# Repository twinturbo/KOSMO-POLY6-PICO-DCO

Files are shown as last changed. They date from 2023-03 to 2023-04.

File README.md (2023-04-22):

# KOSMO-POLY6-PICO-DCO 
This repository contains KICAD Schematics, PCB and front panel to build a 6 voice Raspberry Pi Pico Based Digitaly Controlled Oscilator for the "Polykit" Inspired 6 Channel Synth in Kosmo Format [Look Mum No Computer LMNK]. The credit for the desigin and code goes to the original Project by Jan Knipper AKA PolyKit [PolyKit DCO](https://github.com/polykit/pico-dco)

This project requires a Raspbery Pi Pico MCU.

Parts of the following information are by Jan AKA Polykit from the original repository

## About KOSMO-POLY6
The [POLY6](https://github.com/twinturbo/KOSMO-POLY6) GIT contains the details of the porject as a whole, this is one module.

Other modules in the line up are

- KOSMO-POLY6-PICO-DCO - Complete [ DCO ](https://github.com/twinturbo/KOSMO-POLY6-PICO-DCO)
- KOSMO-POLY6-DRUID-DCO -(TBD).
- KOSMO-POLY6-JACKS - Complete. [ JACKS ](https://github.com/twinturbo/KOSMO-POLY6-JACKS)
- KOSMO-POLY6-MIX - In design.
- KOSMO-POLY6-ADSR - In Production with JLCPCB.
- KOSMO-POLY6-VCA - In design.
- KOSMO-POLY6-CONTROLS - (TBD).
- KOSMO-POLY6 Filter - (TBD).
- KOSMO-POLY6-PG Programmer - (TBD)
- KOSMO-POLY6-MetricST-Front-Panel - (TBD)

# KOSMO-POLY6-PICO-DCO Details

The DCO utilises a Raspbery PI Pico using it's PWM Pins to generate a highly accurate frequency and gate signals. It can be controlled by USB MIDI or Standard 5 Pin serial MIDI. The analog oscillator part is based on the Juno 106 and generates sawtooth and square wave signal with a 10Vpp amplitude. Amplitude compensation is done by a smoothed PWM signal coming from the Pico.

## Key features

- Digitally controlled analog oscillator using a Raspberry Pi Pico
- Up to six voices
- Voice stacking             ------ [ requires sub control board ] See > Not Done
- Detuning of voices         ------ [ requires sub control board ] See > Not Done
- Frequency modulation (FM)  ------ [ requires sub control board ] See > Not Done
- Separate gate signal 
- DIN MIDI serial input
- USB MIDI input
- MIDI pitch bend (Via MIDI CC )
- Portamento with adjustable speed ( Via MIDI CC )
- Voltage and Midi telltale LED's
- Power pass through for sub modules.

## How does Jan's Sound & Look
These are examples of how the originator Jan Knipper's sound.
This is how it sounds: 

- [Ramp sample](https://soundcloud.com/polykit/pico-dco-ramp) 
- [Pulse sample](https://soundcloud.com/polykit/pico-dco-pulse) 
- [Polyphonic sample](https://soundcloud.com/polykit/pico-dco-polyphonic)

And in use with Jan 
- Youtube[Tube](https://www.youtube.com/watch?v=vj-DSh6yfM0)
- Youtube[Tube](https://www.youtube.com/watch?v=go1mErOdtsU)

## Schematics and PCB
Schematics in Kicad format can be found for the PCB and Front Panel

[MAIN-BOARD](HARDWARE/MAIN-BOARD) 
[MAIN-BOARD](HARDWARE/FRONT_PANEL) 

Gerber files for the PCB and front panel can be found [here](HARDWARE\PCB-PRINTS).

## Pictures 
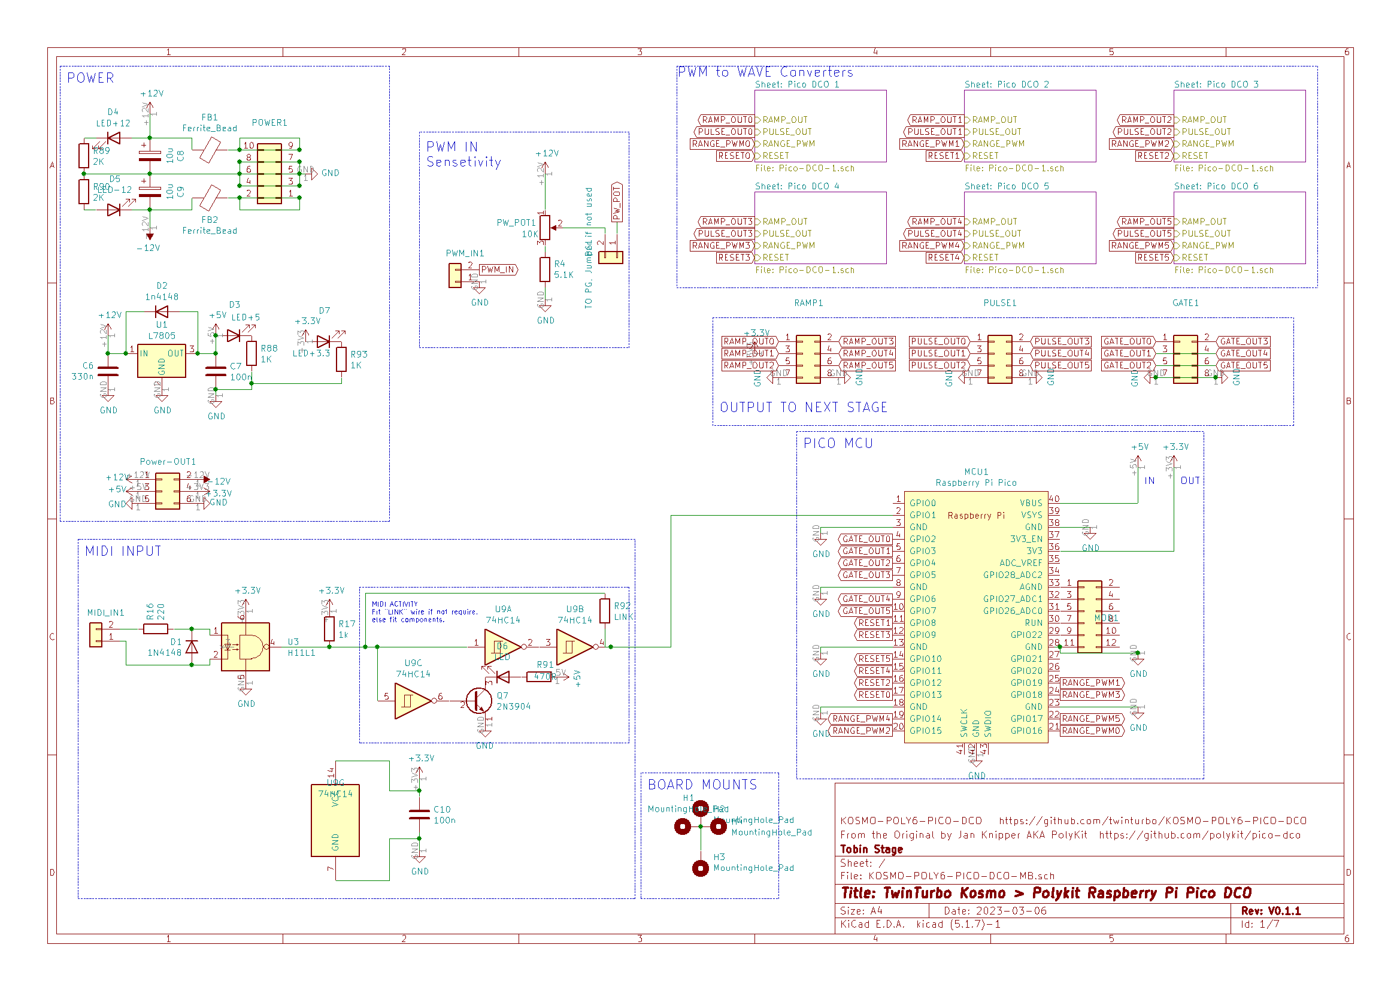
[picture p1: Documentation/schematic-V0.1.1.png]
KOSMO-POLY6-PICO SCHEMATIC

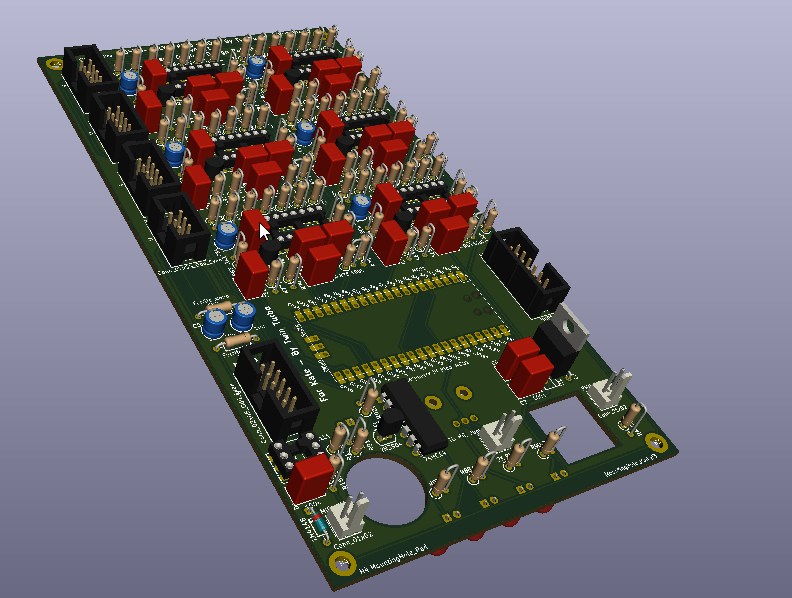
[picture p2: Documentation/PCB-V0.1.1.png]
KOSMO-POLY6-PICO PCB

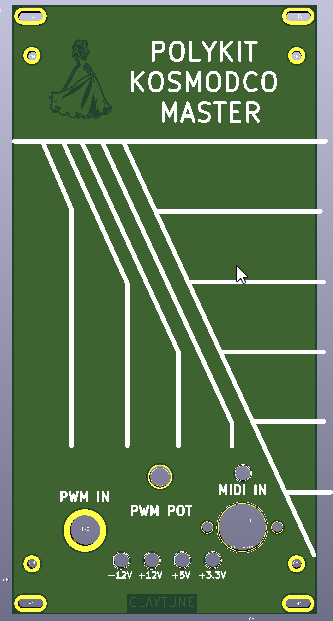
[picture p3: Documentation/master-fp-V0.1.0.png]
KOSMO-POLY6-PICO Front Panel

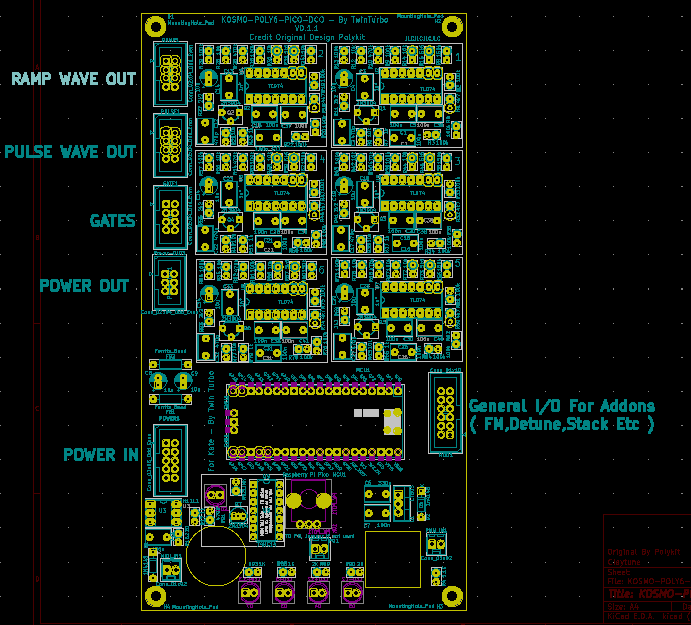
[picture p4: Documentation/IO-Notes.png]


## Installation on the paspbery Pi Pico (simple)
The software has been written in C++ and compiled into a uf2 format for the PICO, 

Two files are provided in the software/build folder along with the source code in the software folder

### Disabled Options
pico-dco-optdisab.uf2 is built with the options for FM, STACK and Detune disabled. This is ideal if you don't have these inputs connected.

//#define USE_ADC_STACK_VOICES // gpio 28 (adc 2)

//#define USE_ADC_DETUNE       // gpio 27 (adc 1)

//#define USE_ADC_FM           // gpio 26 (adc 0)

### Enabled Options
pico-dco-options.uf2 has the above options enabled.

#define USE_ADC_STACK_VOICES // gpio 28 (adc 2)

#define USE_ADC_DETUNE       // gpio 27 (adc 1)

#define USE_ADC_FM           // gpio 26 (adc 0)

### Writing to the MCU.

You will need the file on your computer, and whilst plugging in the PICO to USB hold the `BOOTSEL` button. 

The computer should recognise it as a Mass storage device, Copy desired UF2 file  onto the USB mass storage device. The PICO will reboot into operating mode. Note that if you run the bootsel again the file will not be there, it's not possible to confirm the upload.

## Usage

After building the module and installing the Pico should register as USB MIDI device. Alternatively serial MIDI input is available. The DCO listens to note on/note off messages on MIDI channel 1. Pitch bend is also supported. Portamento can be enabled by MIDI CC message #65, portamento time can be adjusted by CC message #5.

MIDI Device in Cakewalk
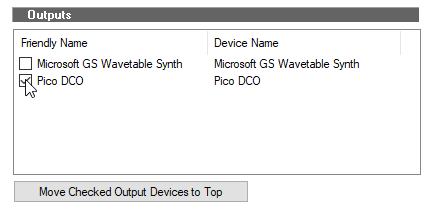
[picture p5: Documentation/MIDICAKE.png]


The 6 notes play all the time, hence there is a need for an ADSR and VCA to close the note off. Each new note played replaces the oldest in the group in a cyclic fashion.

## Detuning, stacking and FM

The built-in analog-to-digital converter can be used to modulate these parameters. You can add an external control voltage (0-3.3V) to that input pins. These features can be disabled by commenting (`//`) the following lines:

As mentioned above, these are not implemented in hardware on this module but a seperate control module needs to be built. 

#define USE_ADC_STACK_VOICES // gpio 28 (adc 2)

#define USE_ADC_DETUNE       // gpio 27 (adc 1)

#define USE_ADC_FM           // gpio 26 (adc 0)

Hardware wise the FM needs to be biased at 1.675v for zero input , the notes on this can be found in the source code **loop void adc_task()**

## Quirks

Initialy the voices will be floating on startup, which if directly outputed ( not through an ADSR/VCA ) may present as noise, as each of the voices is initialised by a key press the noise will go away. 

## Changes 
TwinTurbo 12/3/23 - 
Ref: > https://lookmumnocomputer.discourse.group/t/raspberry-pi-pico-dco/3421/90
updated source code from 0x90 to 0x9F

# References
The Original 
https://github.com/polykit/pico-dco

https://blog.thea.codes/the-design-of-the-juno-dco/

https://electricdruid.net/roland-juno-dcos/

https://www.youtube.com/watch?v=yYnQYF_Xa8g

https://github.com/raspberrypi/pico-examples/tree/master/pio/pwm

https://github.com/raspberrypi/pico-examples/tree/master/pio/pio_blink

https://github.com/raspberrypi/pico-examples/tree/master/pwm/hello_pwm

https://qiita.com/jamjam/items/f2fdd5c072ff348fd809

https://github.com/infovore/pico-example-midi

https://learn.sparkfun.com/tutorials/midi-tutorial/all

http://www.music-software-development.com/midi-tutorial.html

http://midi.teragonaudio.com/tech/midispec/run.htm

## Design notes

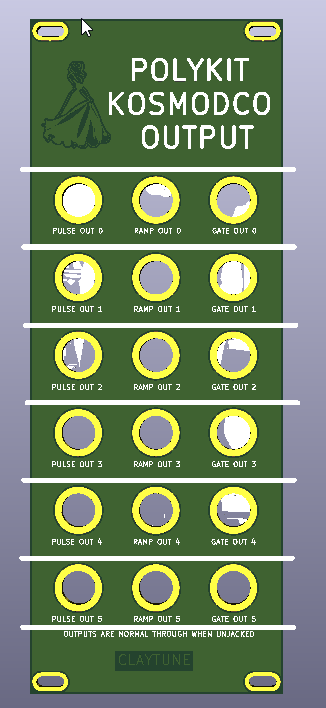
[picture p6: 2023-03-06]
Documentation/jack-fp-V0.1.0.png

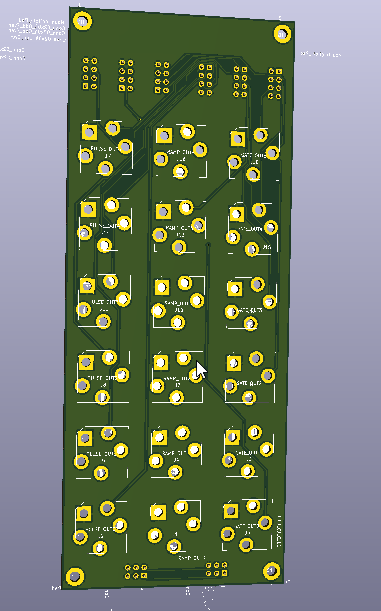
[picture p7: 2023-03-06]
Documentation/jack-pcb-V0.1.0.png

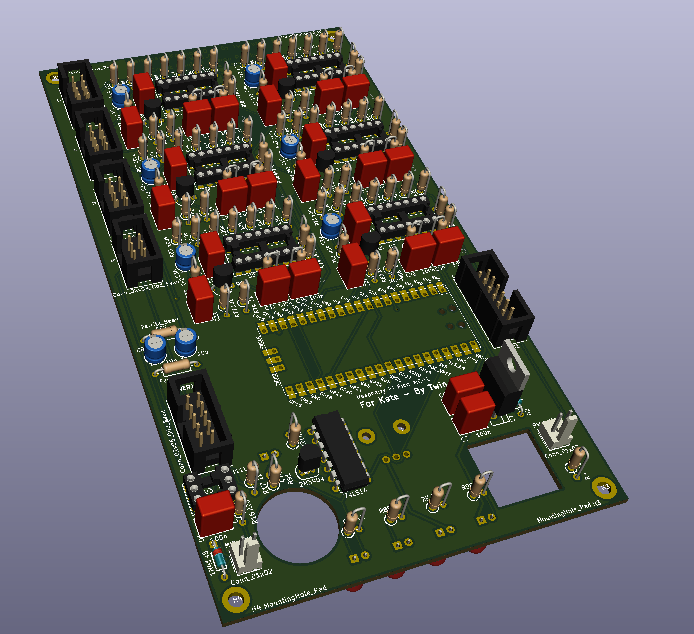
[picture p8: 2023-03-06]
Documentation/master-pcb-V0.1.0.png

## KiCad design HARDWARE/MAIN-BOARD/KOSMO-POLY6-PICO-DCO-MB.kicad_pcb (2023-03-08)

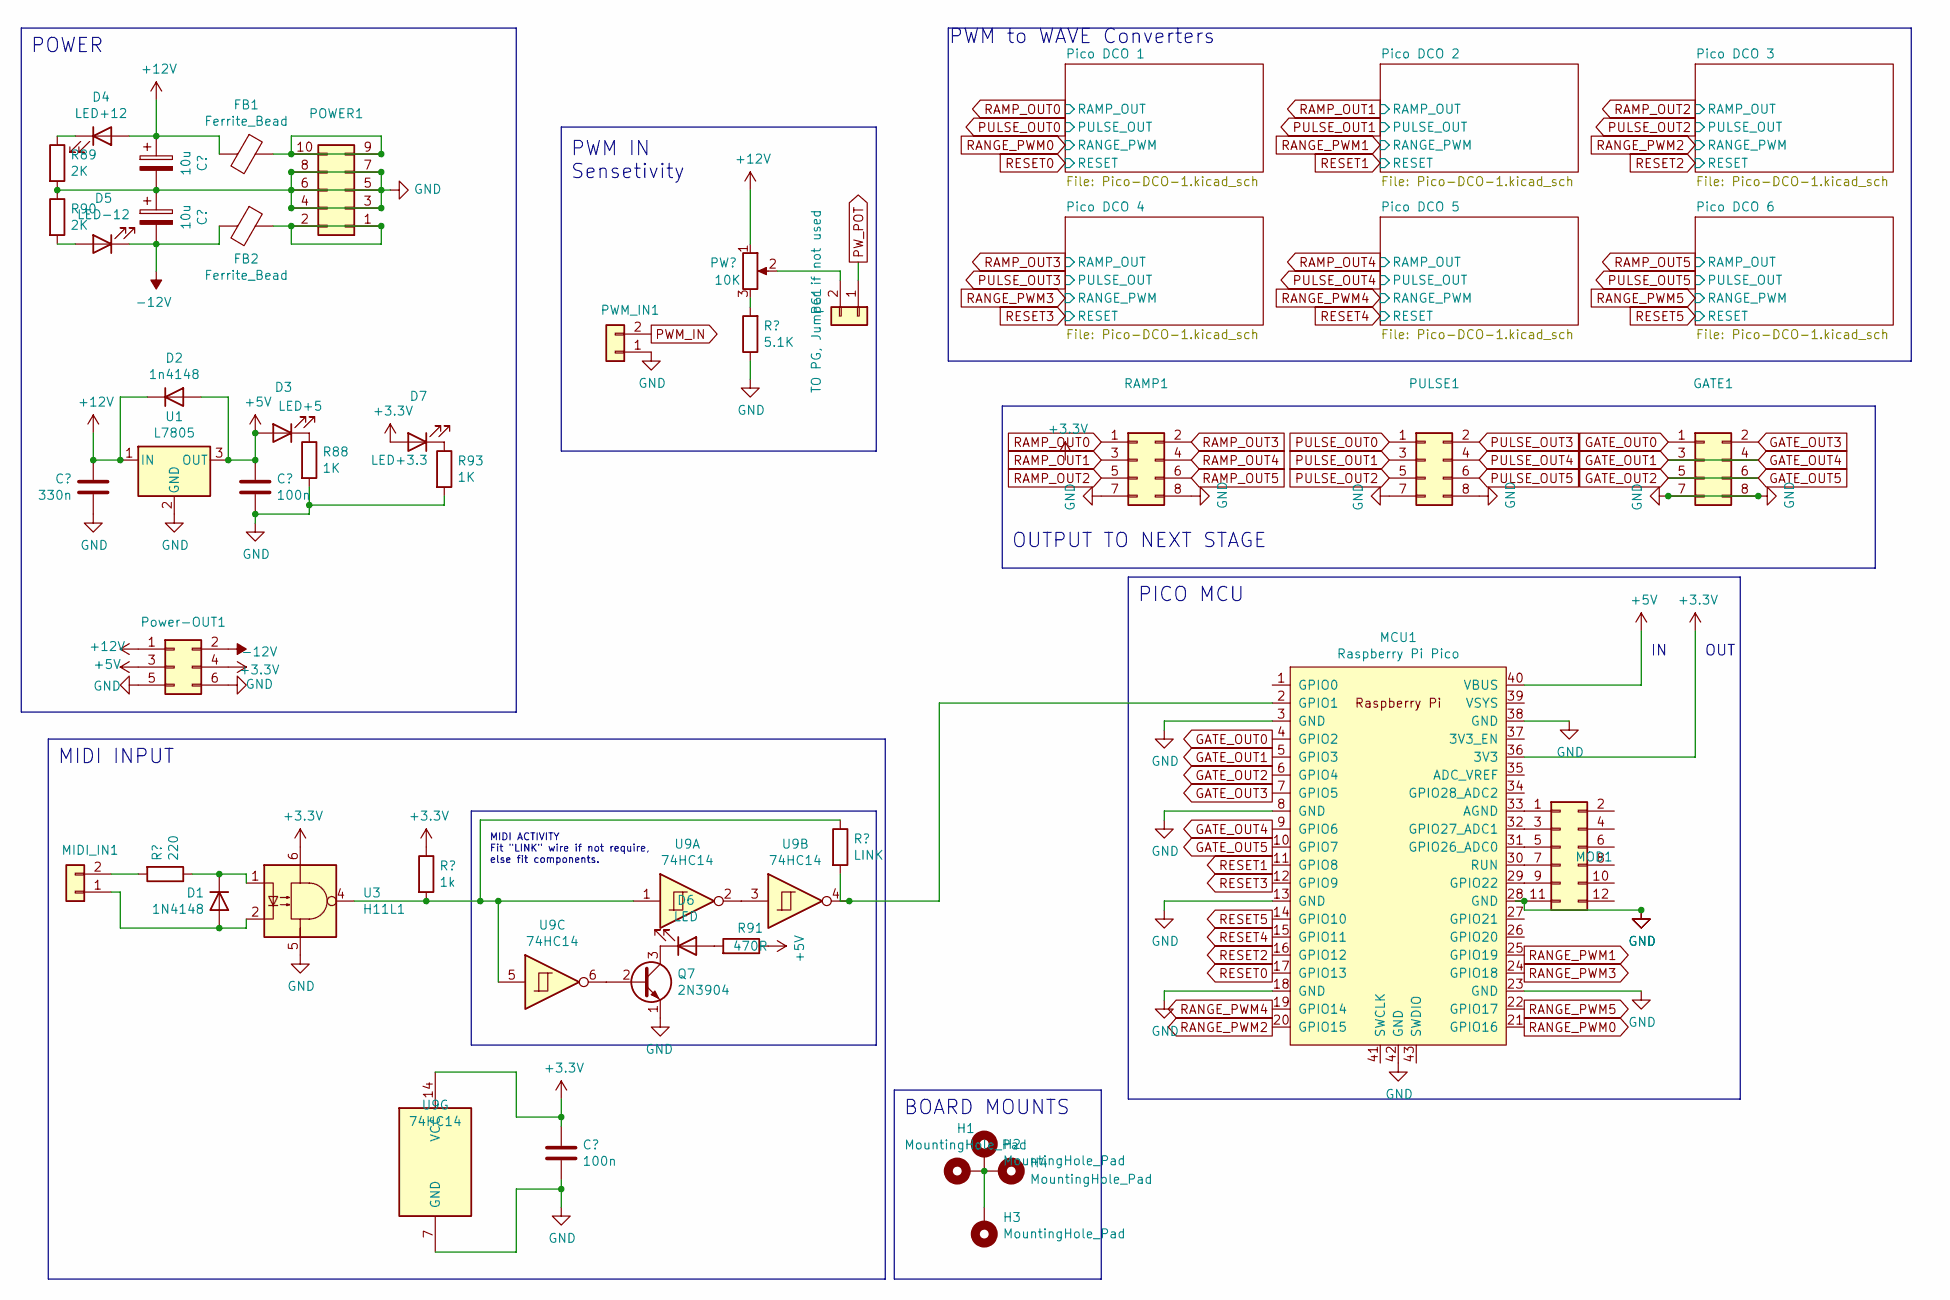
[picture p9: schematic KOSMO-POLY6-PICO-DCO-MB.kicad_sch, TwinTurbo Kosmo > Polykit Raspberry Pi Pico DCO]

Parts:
C6: 330n; C_Rect_L7.2mm_W4.5mm_P5.00mm_FKS2_FKP2_MKS2_MKP2
C7, C10: 100n; C_Rect_L7.2mm_W4.5mm_P5.00mm_FKS2_FKP2_MKS2_MKP2
C8, C9: 10u; CP_Radial_D5.0mm_P2.00mm
D1: 1N4148; D_DO-35_SOD27_P7.62mm_Horizontal
D2: 1n4148; D_DO-35_SOD27_P7.62mm_Horizontal
D3: LED+5; LED_D5.0mm
D4: LED+12; LED_D5.0mm
D5: LED-12; LED_D5.0mm
D6: LED; LED_D5.0mm
D7: LED+3.3; LED_D5.0mm
FB1, FB2: Ferrite_Bead; R_Axial_DIN0207_L6.3mm_D2.5mm_P10.16mm_Horizontal
GATE1: Conn_02x04_Odd_Even; IDC-Header_2x04_P2.54mm_Vertical
H1, H2, H3, H4: MountingHole_Pad; MountingHole_3.2mm_M3_DIN965_Pad
MCU1: Raspberry Pi Pico; RPi_Pico_SMD_TH
MIDI_IN1: Conn_01x02; Molex_KK-254_AE-6410-02A_1x02_P2.54mm_Vertical
MOD1: Conn_01x10; IDC-Header_2x06_P2.54mm_Vertical
PG1: TO PG, Jumper if not used; Molex_KK-254_AE-6410-02A_1x02_P2.54mm_Vertical
POWER1: Conn_02x05_Odd_Even; IDC-Header_2x05_P2.54mm_Vertical
PULSE1: Conn_02x04_Odd_Even; IDC-Header_2x04_P2.54mm_Vertical
PWM_IN1: Conn_01x02; Molex_KK-254_AE-6410-02A_1x02_P2.54mm_Vertical
PW_POT1: 10K; Potentiometer_Alps_RK09K_Single_Vertical
Power-OUT1: Conn_02x04_Odd_Even; IDC-Header_2x03_P2.54mm_Vertical
Q7: 2N3904; TO-92_Inline
R4: 5.1K; R_Axial_DIN0207_L6.3mm_D2.5mm_P2.54mm_Vertical
R16: 220; R_Axial_DIN0207_L6.3mm_D2.5mm_P2.54mm_Vertical
R17: 1k; R_Axial_DIN0207_L6.3mm_D2.5mm_P2.54mm_Vertical
R88, R93: 1K; R_Axial_DIN0207_L6.3mm_D2.5mm_P2.54mm_Vertical
R89, R90: 2K; R_Axial_DIN0207_L6.3mm_D2.5mm_P2.54mm_Vertical
R91: 470R; R_Axial_DIN0207_L6.3mm_D2.5mm_P2.54mm_Vertical
R92: LINK; R_Axial_DIN0207_L6.3mm_D2.5mm_P2.54mm_Vertical
RAMP1: Conn_02x04_Odd_Even; IDC-Header_2x04_P2.54mm_Vertical
U1: L7805; TO-220-3_Vertical
U3: H11L1; DIP-6_W7.62mm_Socket_LongPads
U9: 74HC14; DIP-14_W7.62mm

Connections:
+3V3: C10.1, D7.2 (A), MCU1.36 (3V3), Power-OUT1.4, R17.1, U3.6, U9.14 (VCC)
+5V: C7.1, D2.2 (A), D3.2 (A), MCU1.40 (VBUS), Power-OUT1.3, R91.1, U1.3 (OUT)
+12V: C6.2, C8.1, D2.1 (K), D4.2 (A), FB1.2, PW_POT1.1, Power-OUT1.1, U1.1 (IN); also elsewhere on the board
-12V: C9.2, D5.1 (K), FB2.2, Power-OUT1.2; also elsewhere on the board
GATE_OUT0: GATE1.1, MCU1.4 (GPIO2)
GATE_OUT1: GATE1.3, GATE1.4, MCU1.5 (GPIO3), MCU1.9 (GPIO6)
GATE_OUT2: GATE1.5, GATE1.6, MCU1.6 (GPIO4), MCU1.10 (GPIO7)
GATE_OUT3: GATE1.2, MCU1.7 (GPIO5)
GND: C6.1, C7.2, C8.2, C9.1, C10.2, GATE1.7, GATE1.8, MCU1.3 (GND), MCU1.8 (GND), MCU1.13 (GND), MCU1.18 (GND), MCU1.23 (GND), MCU1.28 (GND), MCU1.38 (GND), MCU1.42 (GND), MOD1.11, POWER1.3, POWER1.4, POWER1.5, POWER1.6, POWER1.7, POWER1.8, PULSE1.7, PULSE1.8, PWM_IN1.1, Power-OUT1.5, Power-OUT1.6, Q7.1 (E), R4.1, R88.2, R89.2, R90.1, R93.2, RAMP1.7, RAMP1.8, U1.2 (GND), U3.5, U9.7 (GND); also elsewhere on the board
unnamed: D1.1 (K), R16.1, U3.1
unnamed: D1.2 (A), MIDI_IN1.1, U3.2
unnamed: D3.1 (K), R88.1
unnamed: D4.1 (K), R89.1
unnamed: D5.2 (A), R90.2
unnamed: D6.1 (K), Q7.3 (C)
unnamed: D6.2 (A), R91.2
unnamed: D7.1 (K), R93.1
unnamed: FB1.1, POWER1.9, POWER1.10
unnamed: FB2.1, POWER1.1, POWER1.2
unnamed: H1.1, H2.1, H3.1, H4.1
unnamed: MCU1.2 (GPIO1), R92.2, U9.4
unnamed: MCU1.29 (GPIO22), MOD1.9
unnamed: MCU1.30 (RUN), MOD1.7
unnamed: MCU1.31 (GPIO26_ADC0), MOD1.5
unnamed: MCU1.32 (GPIO27_ADC1), MOD1.3
unnamed: MCU1.33 (AGND), MOD1.1
unnamed: MIDI_IN1.2, R16.2
unnamed: PG1.2, PW_POT1.2
unnamed: PW_POT1.3, R4.2
unnamed: Q7.2 (B), U9.6
unnamed: R17.2, R92.1, U3.4, U9.1, U9.5
unnamed: U9.2, U9.3
PULSE_OUT0: PULSE1.1; also elsewhere on the board
PULSE_OUT1: PULSE1.3; also elsewhere on the board
PULSE_OUT2: PULSE1.5; also elsewhere on the board
PULSE_OUT3: PULSE1.2; also elsewhere on the board
PULSE_OUT4: PULSE1.4; also elsewhere on the board
PULSE_OUT5: PULSE1.6; also elsewhere on the board
PWM_IN: PWM_IN1.2; also elsewhere on the board
PW_POT: PG1.1; also elsewhere on the board
RAMP_OUT0: RAMP1.1; also elsewhere on the board
RAMP_OUT1: RAMP1.3; also elsewhere on the board
RAMP_OUT2: RAMP1.5; also elsewhere on the board
RAMP_OUT3: RAMP1.2; also elsewhere on the board
RAMP_OUT4: RAMP1.4; also elsewhere on the board
RAMP_OUT5: RAMP1.6; also elsewhere on the board
RANGE_PWM0: MCU1.21 (GPIO16); also elsewhere on the board
RANGE_PWM1: MCU1.25 (GPIO19); also elsewhere on the board
RANGE_PWM2: MCU1.20 (GPIO15); also elsewhere on the board
RANGE_PWM3: MCU1.24 (GPIO18); also elsewhere on the board
RANGE_PWM4: MCU1.19 (GPIO14); also elsewhere on the board
RANGE_PWM5: MCU1.22 (GPIO17); also elsewhere on the board
RESET0: MCU1.17 (GPIO13); also elsewhere on the board
RESET1: MCU1.11 (GPIO8); also elsewhere on the board
RESET2: MCU1.16 (GPIO12); also elsewhere on the board
RESET3: MCU1.12 (GPIO9); also elsewhere on the board
RESET4: MCU1.15 (GPIO11); also elsewhere on the board
RESET5: MCU1.14 (GPIO10); also elsewhere on the board

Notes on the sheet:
POWER
PICO MCU
OUT
PWM to WAVE Converters
MIDI ACTIVITY Fit "LINK" wire if not require, else fit components.
BOARD MOUNTS
PWM IN Sensetivity
MIDI INPUT
OUTPUT TO NEXT STAGE

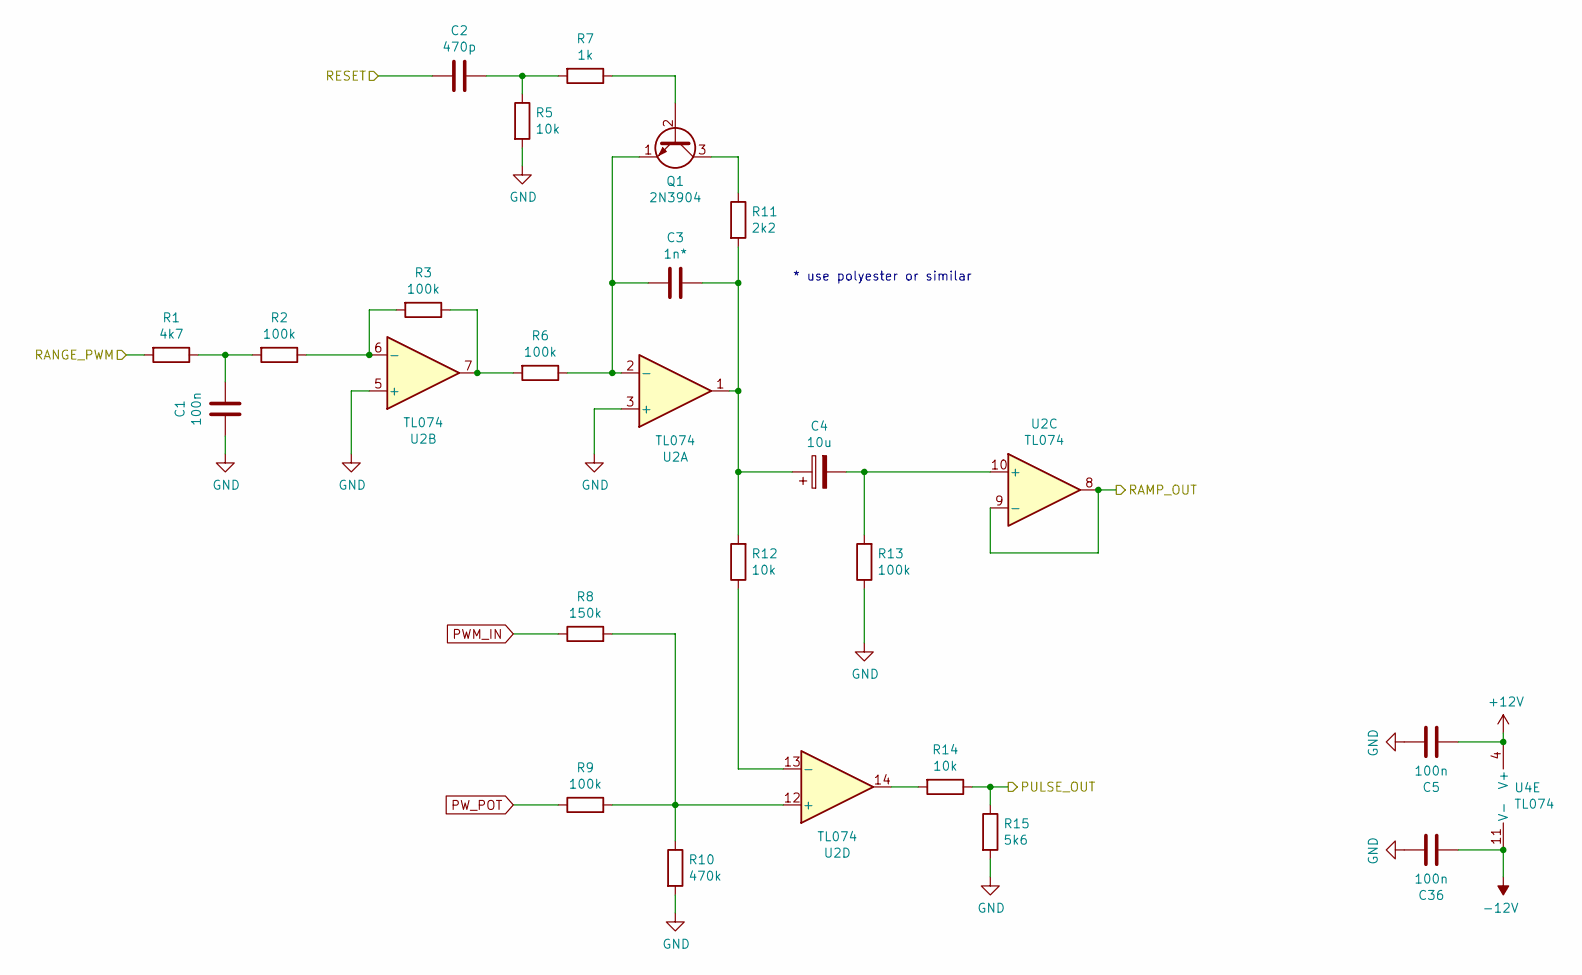
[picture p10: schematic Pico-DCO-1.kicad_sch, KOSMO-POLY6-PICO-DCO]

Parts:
C1, C5, C36: 100n; C_Rect_L7.2mm_W4.5mm_P5.00mm_FKS2_FKP2_MKS2_MKP2
C2: 470p; C_Rect_L7.2mm_W4.5mm_P5.00mm_FKS2_FKP2_MKS2_MKP2
C3: 1n*; C_Rect_L7.2mm_W4.5mm_P5.00mm_FKS2_FKP2_MKS2_MKP2
C4: 10u; CP_Radial_D5.0mm_P2.00mm
Q1: 2N3904; TO-92_Wide
R1: 4k7; R_Axial_DIN0207_L6.3mm_D2.5mm_P2.54mm_Vertical
R2, R3, R6, R9, R13: 100k; R_Axial_DIN0207_L6.3mm_D2.5mm_P2.54mm_Vertical
R5, R12, R14: 10k; R_Axial_DIN0207_L6.3mm_D2.5mm_P2.54mm_Vertical
R7: 1k; R_Axial_DIN0207_L6.3mm_D2.5mm_P2.54mm_Vertical
R8: 150k; R_Axial_DIN0207_L6.3mm_D2.5mm_P2.54mm_Vertical
R10: 470k; R_Axial_DIN0207_L6.3mm_D2.5mm_P2.54mm_Vertical
R11: 2k2; R_Axial_DIN0207_L6.3mm_D2.5mm_P2.54mm_Vertical
R15: 5k6; R_Axial_DIN0207_L6.3mm_D2.5mm_P2.54mm_Vertical
U2, U4: TL074; DIP-14_W7.62mm_Socket_LongPads

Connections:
+12V: C5.2, U2.4 (V+), U4.4 (V+); also elsewhere on the board
-12V: C36.2, U2.11 (V-), U4.11 (V-); also elsewhere on the board
GND: C1.2, C5.1, C36.1, R5.2, R10.2, R13.1, R15.2, U2.3 (+), U2.5 (+), U4.3 (+), U4.5 (+); also elsewhere on the board
unnamed: C1.1, R1.1, R2.2
unnamed: C2.1, R5.1, R7.2
unnamed: C3.1, C4.1, R11.2, R12.2, U2.1
unnamed: C3.2, Q1.1 (E), R6.1, U2.2 (-)
unnamed: C4.2, R13.2, U2.10 (+)
unnamed 16: U4.1; also elsewhere on the board
unnamed 17: U4.2 (-); also elsewhere on the board
unnamed 18: U4.10 (+); also elsewhere on the board
unnamed: Q1.2 (B), R7.1
unnamed: Q1.3 (C), R11.1
unnamed: R2.1, R3.2, U2.6 (-)
unnamed: R3.1, R6.2, U2.7
unnamed: R8.2, R9.2, R10.1, U2.12 (+)
unnamed: R12.1, U2.13 (-)
unnamed: R14.2, U2.14
unnamed 93: U4.6 (-); also elsewhere on the board
unnamed 94: U4.7; also elsewhere on the board
unnamed 95: U4.12 (+); also elsewhere on the board
unnamed 96: U4.13 (-); also elsewhere on the board
unnamed 97: U4.14; also elsewhere on the board
PULSE_OUT0: R14.1, R15.1; also elsewhere on the board
PWM_IN: R8.1; also elsewhere on the board
PW_POT: R9.1; also elsewhere on the board
RAMP_OUT0: U2.8, U2.9 (-); also elsewhere on the board
RAMP_OUT1: U4.8, U4.9 (-); also elsewhere on the board
RANGE_PWM0: R1.2; also elsewhere on the board
RESET0: C2.2; also elsewhere on the board

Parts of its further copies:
C11, C15, C16, C20, C21, C25, C26, C30, C31, C35, C37, C38, C39, C40, C41: 100n; C_Rect_L7.2mm_W4.5mm_P5.00mm_FKS2_FKP2_MKS2_MKP2
C12, C17, C22, C27, C32: 470p; C_Rect_L7.2mm_W4.5mm_P5.00mm_FKS2_FKP2_MKS2_MKP2
C13, C18, C23, C28, C33: 1n*; C_Rect_L7.2mm_W4.5mm_P5.00mm_FKS2_FKP2_MKS2_MKP2
C14, C19, C24, C29, C34: 10u; CP_Radial_D5.0mm_P2.00mm
Q2, Q3, Q4, Q5, Q6: 2N3904; TO-92_Wide
R18, R32, R46, R60, R74: 4k7; R_Axial_DIN0207_L6.3mm_D2.5mm_P2.54mm_Vertical
R19, R20, R22, R25, R29, R33, R34, R36, R39, R43, R47, R48, R50, R53, R57, R61, R62, R64, R67, R71, R75, R76, R78, R81, R85: 100k; R_Axial_DIN0207_L6.3mm_D2.5mm_P2.54mm_Vertical
R21, R28, R30, R35, R42, R44, R49, R56, R58, R63, R70, R72, R77, R84, R86: 10k; R_Axial_DIN0207_L6.3mm_D2.5mm_P2.54mm_Vertical
R23, R37, R51, R65, R79: 1k; R_Axial_DIN0207_L6.3mm_D2.5mm_P2.54mm_Vertical
R24, R38, R52, R66, R80: 150k; R_Axial_DIN0207_L6.3mm_D2.5mm_P2.54mm_Vertical
R26, R40, R54, R68, R82: 470k; R_Axial_DIN0207_L6.3mm_D2.5mm_P2.54mm_Vertical
R27, R41, R55, R69, R83: 2k2; R_Axial_DIN0207_L6.3mm_D2.5mm_P2.54mm_Vertical
R31, R45, R59, R73, R87: 5k6; R_Axial_DIN0207_L6.3mm_D2.5mm_P2.54mm_Vertical
U5, U6, U7, U8: TL074; DIP-14_W7.62mm_Socket_LongPads

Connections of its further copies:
+12V: C15.2, C20.2, C25.2, C30.2, C35.2, U5.4 (V+), U6.4 (V+), U7.4 (V+), U8.4 (V+); also elsewhere on the board
-12V: C37.2, C38.2, C39.2, C40.2, C41.2, U5.11 (V-), U6.11 (V-), U7.11 (V-), U8.11 (V-); also elsewhere on the board
GND: C11.2, C15.1, C16.2, C20.1, C21.2, C25.1, C26.2, C30.1, C31.2, C35.1, C37.1, C38.1, C39.1, C40.1, C41.1, R21.2, R26.2, R29.1, R31.2, R35.2, R40.2, R43.1, R45.2, R49.2, R54.2, R57.1, R59.2, R63.2, R68.2, R71.1, R73.2, R77.2, R82.2, R85.1, R87.2, U5.3 (+), U5.5 (+), U6.3 (+), U6.5 (+), U7.3 (+), U7.5 (+), U8.3 (+), U8.5 (+); also elsewhere on the board
unnamed: C11.1, R18.1, R19.2
unnamed: C12.1, R21.1, R23.2
unnamed 16: C13.1, C14.1, R27.2, R28.2; also elsewhere on the board
unnamed 17: C13.2, Q2.1 (E), R22.1; also elsewhere on the board
unnamed 18: C14.2, R29.2; also elsewhere on the board
unnamed: C16.1, R32.1, R33.2
unnamed: C17.1, R35.1, R37.2
unnamed: C18.1, C19.1, R41.2, R42.2, U5.1
unnamed: C18.2, Q3.1 (E), R36.1, U5.2 (-)
unnamed: C19.2, R43.2, U5.10 (+)
unnamed: C21.1, R46.1, R47.2
unnamed: C22.1, R49.1, R51.2
unnamed: C23.1, C24.1, R55.2, R56.2, U6.1
unnamed: C23.2, Q4.1 (E), R50.1, U6.2 (-)
unnamed: C24.2, R57.2, U6.10 (+)
unnamed: C26.1, R60.1, R61.2
unnamed: C27.1, R63.1, R65.2
unnamed: C28.1, C29.1, R69.2, R70.2, U7.1
unnamed: C28.2, Q5.1 (E), R64.1, U7.2 (-)
unnamed: C29.2, R71.2, U7.10 (+)
unnamed: C31.1, R74.1, R75.2
unnamed: C32.1, R77.1, R79.2
unnamed: C33.1, C34.1, R83.2, R84.2, U8.1
unnamed: C33.2, Q6.1 (E), R78.1, U8.2 (-)
unnamed: C34.2, R85.2, U8.10 (+)
unnamed: Q2.2 (B), R23.1
unnamed: Q2.3 (C), R27.1
unnamed: Q3.2 (B), R37.1
unnamed: Q3.3 (C), R41.1
unnamed: Q4.2 (B), R51.1
unnamed: Q4.3 (C), R55.1
unnamed: Q5.2 (B), R65.1
unnamed: Q5.3 (C), R69.1
unnamed: Q6.2 (B), R79.1
unnamed: Q6.3 (C), R83.1
unnamed 93: R19.1, R20.2; also elsewhere on the board
unnamed 94: R20.1, R22.2; also elsewhere on the board
unnamed 95: R24.2, R25.2, R26.1; also elsewhere on the board
unnamed 96: R28.1; also elsewhere on the board
unnamed 97: R30.2; also elsewhere on the board
unnamed: R33.1, R34.2, U5.6 (-)
unnamed: R34.1, R36.2, U5.7
unnamed: R38.2, R39.2, R40.1, U5.12 (+)
unnamed: R42.1, U5.13 (-)
unnamed: R44.2, U5.14
unnamed: R47.1, R48.2, U6.6 (-)
unnamed: R48.1, R50.2, U6.7
unnamed: R52.2, R53.2, R54.1, U6.12 (+)
unnamed: R56.1, U6.13 (-)
unnamed: R58.2, U6.14
unnamed: R61.1, R62.2, U7.6 (-)
unnamed: R62.1, R64.2, U7.7
unnamed: R66.2, R67.2, R68.1, U7.12 (+)
unnamed: R70.1, U7.13 (-)
unnamed: R72.2, U7.14
unnamed: R75.1, R76.2, U8.6 (-)
unnamed: R76.1, R78.2, U8.7
unnamed: R80.2, R81.2, R82.1, U8.12 (+)
unnamed: R84.1, U8.13 (-)
unnamed: R86.2, U8.14
PULSE_OUT1: R30.1, R31.1; also elsewhere on the board
PULSE_OUT2: R44.1, R45.1; also elsewhere on the board
PULSE_OUT3: R58.1, R59.1; also elsewhere on the board
PULSE_OUT4: R72.1, R73.1; also elsewhere on the board
PULSE_OUT5: R86.1, R87.1; also elsewhere on the board
PWM_IN: R24.1, R38.1, R52.1, R66.1, R80.1; also elsewhere on the board
PW_POT: R25.1, R39.1, R53.1, R67.1, R81.1; also elsewhere on the board
RAMP_OUT2: U5.8, U5.9 (-); also elsewhere on the board
RAMP_OUT3: U6.8, U6.9 (-); also elsewhere on the board
RAMP_OUT4: U7.8, U7.9 (-); also elsewhere on the board
RAMP_OUT5: U8.8, U8.9 (-); also elsewhere on the board
RANGE_PWM1: R18.2; also elsewhere on the board
RANGE_PWM2: R32.2; also elsewhere on the board
RANGE_PWM3: R46.2; also elsewhere on the board
RANGE_PWM4: R60.2; also elsewhere on the board
RANGE_PWM5: R74.2; also elsewhere on the board
RESET1: C12.2; also elsewhere on the board
RESET2: C17.2; also elsewhere on the board
RESET3: C22.2; also elsewhere on the board
RESET4: C27.2; also elsewhere on the board
RESET5: C32.2; also elsewhere on the board

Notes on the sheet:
* use polyester or similar

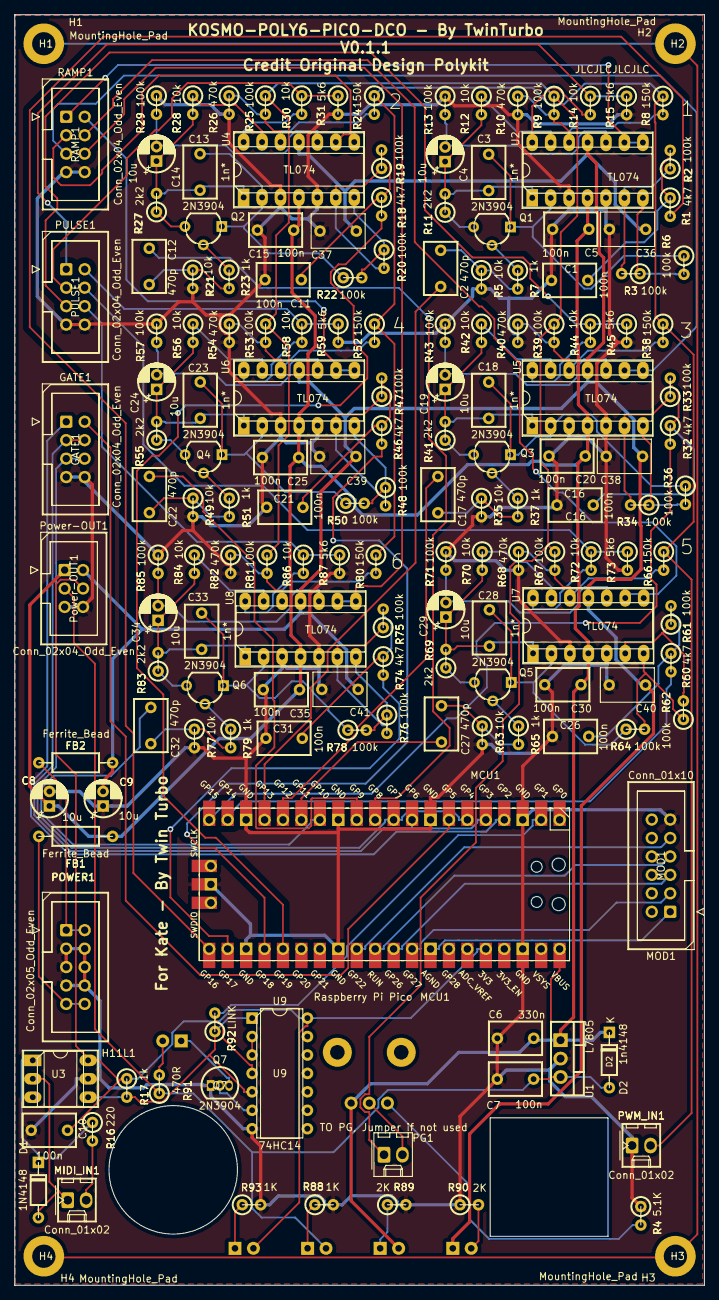
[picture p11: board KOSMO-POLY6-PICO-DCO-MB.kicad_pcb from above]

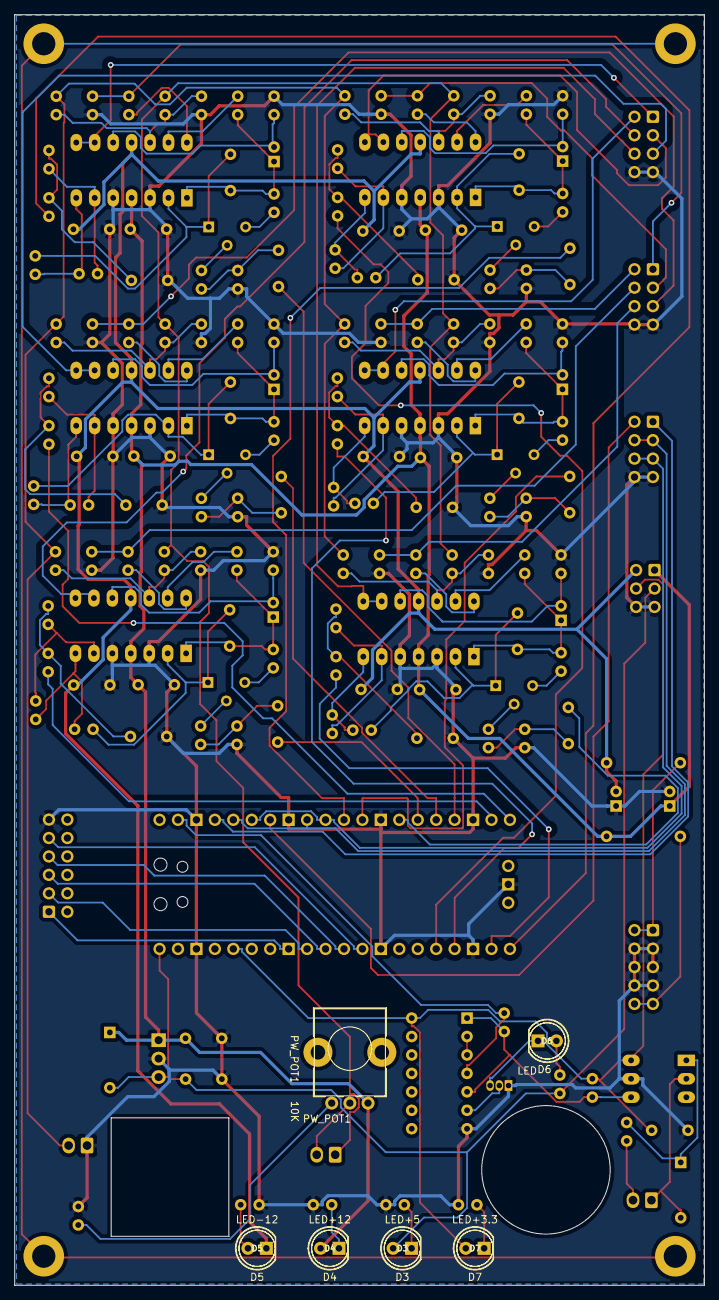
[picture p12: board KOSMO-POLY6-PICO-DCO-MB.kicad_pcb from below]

Board: 2 copper layers, 95.0 x 175.0 mm, 174 parts (6 on the bottom side), 130 nets.

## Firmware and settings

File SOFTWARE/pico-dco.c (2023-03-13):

#include <stdio.h>
#include <stdlib.h>
#include <math.h>
#include "pico/stdlib.h"
#include "hardware/gpio.h"
#include "hardware/adc.h"
#include "hardware/pio.h"
#include "hardware/clocks.h"
#include "pico-dco.pio.h"
#include "hardware/pwm.h"
#include "bsp/board.h"
#include "tusb.h"
#include "hardware/uart.h"

#define NUM_VOICES 6
#define MIDI_CHANNEL 1
#define USE_ADC_STACK_VOICES // gpio 28 (adc 2)
#define USE_ADC_DETUNE       // gpio 27 (adc 1)
#define USE_ADC_FM           // gpio 26 (adc 0)

uint STACK_VOICES = 1;
float DETUNE = 0.0f, LAST_DETUNE = 0.0f;
float FM_VALUE = 0.0f;  
float LAST_FM = 0.0f;

// Scale factor for FM. Controls how intense the effect is at maximum input voltage.
// Units: Hertz.
float FM_INTENSITY = 5.0f;          

const float BASE_NOTE = 440.0f;
const uint8_t RESET_PINS[NUM_VOICES] = {13, 8, 12, 9, 11, 10};
const uint8_t RANGE_PINS[NUM_VOICES] = {16, 19, 15, 18, 14, 17};
const uint8_t GATE_PINS[NUM_VOICES] = {2, 3, 4, 5, 6, 7};
const uint8_t VOICE_TO_PIO[NUM_VOICES] = {0, 0, 0, 0, 1, 1};
const uint8_t VOICE_TO_SM[NUM_VOICES] = {0, 1, 2, 3, 0, 1};
const uint16_t DIV_COUNTER = 1250;
uint8_t RANGE_PWM_SLICES[NUM_VOICES];

uint32_t VOICES[NUM_VOICES];
uint8_t VOICE_NOTES[NUM_VOICES];
uint8_t VOICE_GATE[NUM_VOICES];

uint8_t NEXT_VOICE = 0;
uint32_t LED_BLINK_START = 0;
PIO pio[2] = {pio0, pio1};
uint8_t midi_serial_status = 0;
uint16_t midi_pitch_bend = 0x2000, last_midi_pitch_bend = 0x2000;
bool portamento = false;
uint8_t portamento_time = 0, portamento_start = 0, portamento_stop = 0;
float portamento_cur_freq = 0.0f;

void init_sm(PIO pio, uint sm, uint offset, uint pin);
void set_frequency(PIO pio, uint sm, float freq);
float get_freq_from_midi_note(uint8_t note);
void led_blinking_task();
uint8_t get_free_voice();
void usb_midi_task();
void serial_midi_task();
void note_on(uint8_t note, uint8_t velocity);
void note_off(uint8_t note);
void voice_task();
void adc_task();
long map(long x, long in_min, long in_max, long out_min, long out_max);

int main() {
    board_init();
    tusb_init();

    // use more accurate PWM mode for buck-boost converter
    gpio_init(23);
    gpio_set_dir(23, GPIO_OUT);
    gpio_put(23, 1);

    // init serial midi
    uart_init(uart0, 31250);
    uart_set_fifo_enabled(uart0, true);
    gpio_set_function(0, GPIO_FUNC_UART);
    gpio_set_function(1, GPIO_FUNC_UART);

    // pwm init
    for (int i=0; i<NUM_VOICES; i++) {
        gpio_set_function(RANGE_PINS[i], GPIO_FUNC_PWM);
        RANGE_PWM_SLICES[i] = pwm_gpio_to_slice_num(RANGE_PINS[i]);
        pwm_set_wrap(RANGE_PWM_SLICES[i], DIV_COUNTER);
        pwm_set_enabled(RANGE_PWM_SLICES[i], true);
    }

    // pio init
    uint offset[2];
    offset[0] = pio_add_program(pio[0], &frequency_program);
    offset[1] = pio_add_program(pio[1], &frequency_program);
    for (int i=0; i<NUM_VOICES; i++) {
        init_sm(pio[VOICE_TO_PIO[i]], VOICE_TO_SM[i], offset[VOICE_TO_PIO[i]], RESET_PINS[i]);
    }

    // gate gpio init
    for (int i=0; i<NUM_VOICES; i++) {
        gpio_init(GATE_PINS[i]);
        gpio_set_dir(GATE_PINS[i], GPIO_OUT);
    }

    // adc init
    #if defined(USE_ADC_STACK_VOICES) || defined(USE_ADC_DETUNE) || defined(USE_ADC_FM) 
    adc_init();
    #ifdef USE_ADC_DETUNE
    adc_gpio_init(27);
    #endif
    #ifdef USE_ADC_STACK_VOICES
    adc_gpio_init(28);
    #endif
    #ifdef USE_ADC_FM
    adc_gpio_init(26);
    #endif
    #endif

    // init voices
    for (int i=0; i<NUM_VOICES; i++) {
        VOICES[i] = 0;
        VOICE_GATE[i] = 0;
    }

    while (1) {
        tud_task();
        usb_midi_task();
        serial_midi_task();
        voice_task();
        #if defined(USE_ADC_STACK_VOICES) || defined(USE_ADC_DETUNE) || defined(USE_ADC_FM)
        adc_task();
        #endif
        led_blinking_task();
    }
}

void init_sm(PIO pio, uint sm, uint offset, uint pin) {
    init_sm_pin(pio, sm, offset, pin);
    pio_sm_set_enabled(pio, sm, true);
}

void set_frequency(PIO pio, uint sm, float freq) {
    uint32_t clk_div = clock_get_hz(clk_sys) / 2 / freq;
    if (freq == 0) clk_div = 0;
    pio_sm_put(pio, sm, clk_div);
    pio_sm_exec(pio, sm, pio_encode_pull(false, false));
    pio_sm_exec(pio, sm, pio_encode_out(pio_y, 32));
}

float get_freq_from_midi_note(uint8_t note) {
    if (portamento && portamento_start != 0 && portamento_stop != 0) {
        float freq1 = pow(2, (portamento_start-69)/12.0f) * BASE_NOTE;
        float freq2 = pow(2, (portamento_stop-69)/12.0f) * BASE_NOTE;
        if (portamento_cur_freq == 0) {
            portamento_cur_freq = freq1;
        } else {
            if (freq1 < freq2) {
                portamento_cur_freq += 1.0f/(portamento_time+1);
                if (portamento_cur_freq > freq2) portamento_cur_freq = freq2;
            } else {
                portamento_cur_freq -= 1.0f/(portamento_time+1);
                if (portamento_cur_freq < freq2) portamento_cur_freq = freq2;
            }
        }
        return portamento_cur_freq;
    }

    return pow(2, (note-69)/12.0f) * BASE_NOTE;
}

void usb_midi_task() {
    if (tud_midi_available() < 4) return;

    uint8_t buff[4];

    LED_BLINK_START = board_millis();
    board_led_write(true);

    if (tud_midi_packet_read(buff)) {
        if (buff[1] == (0x90 | (MIDI_CHANNEL-1))) {
            if (buff[3] > 0) {
                note_on(buff[2], buff[3]);
            } else {
                note_off(buff[2]);
            }
        }

        if (buff[1] == (0x80 | (MIDI_CHANNEL-1))) {
            note_off(buff[2]);
        }

        if (buff[1] == (0xE0 | (MIDI_CHANNEL-1))) {
            midi_pitch_bend = buff[2] | (buff[3]<<7);
        }

        if (midi_serial_status == (0xB0 | (MIDI_CHANNEL-1))) {
            if (buff[2] == 5) { // portamento time
                portamento_time = buff[3];
            }
            if (buff[2] == 65) { // portamento on/off
                portamento = buff[3] > 63;
            }
        }
    }
}

void serial_midi_task() {
    if (!uart_is_readable(uart0)) return;

    uint8_t lsb = 0, msb = 0;

    uint8_t data = uart_getc(uart0);
    
    LED_BLINK_START = board_millis();
    board_led_write(true);

    // status
    if (data >= 0xF0 && data <= 0xF7) {
        midi_serial_status = 0;
        return;
    }

    // realtime message
    if (data >= 0xF8 && data <= 0xFF) {
        return;
    }

    if (data >= 0x80 && data <= 0xEF) {
        midi_serial_status = data;
    }
//https://lookmumnocomputer.discourse.group/t/raspberry-pi-pico-dco/3421/90
// updated from 0x90 to 0x9F RC 12/3/23
    if (midi_serial_status >= 0x80 && midi_serial_status <= 0x9F ||
        midi_serial_status >= 0xB0 && midi_serial_status <= 0xBF || // cc messages
        midi_serial_status >= 0xE0 && midi_serial_status <= 0xEF) {

        lsb = uart_getc(uart0);
        msb = uart_getc(uart0);
    }

    if (midi_serial_status == (0x90 | (MIDI_CHANNEL-1))) {
        if (msb > 0) {
            note_on(lsb, msb);
        } else {
            note_off(lsb);
        }
    }

    if (midi_serial_status == (0x80 | (MIDI_CHANNEL-1))) {
        note_off(lsb);
    }

    if (midi_serial_status == (0xE0 | (MIDI_CHANNEL-1))) {
        midi_pitch_bend = lsb | (msb<<7);
    }

    if (midi_serial_status == (0xB0 | (MIDI_CHANNEL-1))) {
        if (lsb == 5) { // portamento time
            portamento_time = msb;
        }
        if (lsb == 65) { // portamento on/off
             portamento = msb > 63;
        }
    }
}

void note_on(uint8_t note, uint8_t velocity) {
    if (STACK_VOICES < 2) {
        for (int i=0; i<NUM_VOICES; i++) {
            if (VOICE_NOTES[i] == note && VOICE_GATE[i]) return; // note already playing
        }
    }
    for (int i=0; i<STACK_VOICES; i++) {
        uint8_t voice_num = get_free_voice();

        VOICES[voice_num] = board_millis();
        VOICE_NOTES[voice_num] = note;
        VOICE_GATE[voice_num] = 1;

        float freq = get_freq_from_midi_note(note) * (1 + (pow(-1, i) * DETUNE));
        set_frequency(pio[VOICE_TO_PIO[voice_num]], VOICE_TO_SM[voice_num], freq);
        // amplitude adjustment
        pwm_set_chan_level(RANGE_PWM_SLICES[voice_num], pwm_gpio_to_channel(RANGE_PINS[voice_num]), (int)(DIV_COUNTER*(freq*0.00025f-1/(100*freq))));
        // gate on
        gpio_put(GATE_PINS[voice_num], 1);
    }
    if (portamento) {
        if (portamento_start == 0) {
            portamento_start = note;
            portamento_cur_freq = 0.0f;
        } else {
            portamento_stop = note;
        }
    }
    last_midi_pitch_bend = 0;
}

void note_off(uint8_t note) {
    // gate off
    for (int i=0; i<NUM_VOICES; i++) {
        if (VOICE_NOTES[i] == note) {
            gpio_put(GATE_PINS[i], 0);

            //VOICE_NOTES[i] = 0;
            VOICES[i] = 0;
            VOICE_GATE[i] = 0;
        }
    }
    if (portamento_stop == note) {
        portamento_start = portamento_stop;
        portamento_stop = 0;
        portamento_cur_freq = 0.0f;
    }
    /*
    if (portamento_start == note) {
        portamento_stop = 0;
        portamento_cur_freq = 0.0f;
    }
    */
}

uint8_t get_free_voice() {
    uint32_t oldest_time = board_millis();
    uint8_t oldest_voice = 0;

    for (int i=0; i<NUM_VOICES; i++) {
        uint8_t n = (NEXT_VOICE+i)%NUM_VOICES;

        if (VOICE_GATE[n] == 0) {
            NEXT_VOICE = (n+1)%NUM_VOICES;
            return n;
        }

        if (VOICES[i]<oldest_time) {
            oldest_time = VOICES[i];
            oldest_voice = i;
        }
    }

    NEXT_VOICE = (oldest_voice+1)%NUM_VOICES;
    return oldest_voice;
}

void voice_task() {
    if (midi_pitch_bend != last_midi_pitch_bend || DETUNE != LAST_DETUNE || portamento || FM_VALUE != LAST_FM) {

        last_midi_pitch_bend = midi_pitch_bend;
        LAST_DETUNE = DETUNE;
        LAST_FM = FM_VALUE;

        for (int i=0; i<NUM_VOICES; i++) {

            float freq = get_freq_from_midi_note(VOICE_NOTES[i]) * (1 + (pow(-1, i) * DETUNE));

            freq += FM_VALUE * FM_INTENSITY; // Add linear frequency modulation
            
            freq = freq-(freq*((0x2000-midi_pitch_bend)/67000.0f));
            set_frequency(pio[VOICE_TO_PIO[i]], VOICE_TO_SM[i], freq);
            pwm_set_chan_level(RANGE_PWM_SLICES[i], pwm_gpio_to_channel(RANGE_PINS[i]), (int)(DIV_COUNTER*(freq*0.00025f-1/(100*freq))));
        }
    }
}

void adc_task() {
    uint16_t raw;

    #ifdef USE_ADC_DETUNE
    adc_select_input(1);
    raw = adc_read();
    DETUNE = map(raw, 0, 4095, 0, 50)/1000.0f;
    #endif

    #ifdef USE_ADC_STACK_VOICES
    adc_select_input(2);
    raw = adc_read();
    STACK_VOICES = map(raw, 0, 4000, 1, NUM_VOICES);
    #endif

    #ifdef USE_ADC_FM

    adc_select_input(0);
    raw = adc_read();

    // This input assumes a centre FM value of 2^11 = 2048, as the 
    // ADCs are unsigned. This can be overcome in hardware with a fixed 
    // voltage offset. The range of the Pico's ADCs is 3.3V, so a fixed 
    // offset of 1.65V is needed.
    int signed_raw = raw - (1 << 11);
    FM_VALUE = (float) signed_raw / (float) (1 << 11);
    #endif

}

long map(long x, long in_min, long in_max, long out_min, long out_max) {
  return (x - in_min) * (out_max - out_min) / (in_max - in_min) + out_min;
}

void led_blinking_task() {
    if (board_millis() - LED_BLINK_START < 50) return;
    board_led_write(false);
}

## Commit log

2023-03-06 1st Fix
    [1U-One.kicad_pcb, 2U-JackSplit.kicad_pcb, 2U-One.kicad_pcb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]
2023-03-06 baord ready
    [KOSMO-POLY6-PICO-DCO-MB.kicad_pcb, KOSMO-POLY6-PICO-DCO-MB.sch, Pico-DCO-1.sch]
2023-03-08 Added jumper on PWM pot to go to future PG Programmer
    [KOSMO-POLY6-PICO-DCO-MB-B_Cu.gbr, KOSMO-POLY6-PICO-DCO-MB-B_Fab.gbr, KOSMO-POLY6-PICO-DCO-MB-B_Mask.gbr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]
2023-03-13 KICAD7 FIXLAYER
    [KOSMO-POLY6-PICO-DCO-MB-B_Cu.gbr, KOSMO-POLY6-PICO-DCO-MB-B_Fab.gbr, KOSMO-POLY6-PICO-DCO-MB-B_Mask.gbr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]
